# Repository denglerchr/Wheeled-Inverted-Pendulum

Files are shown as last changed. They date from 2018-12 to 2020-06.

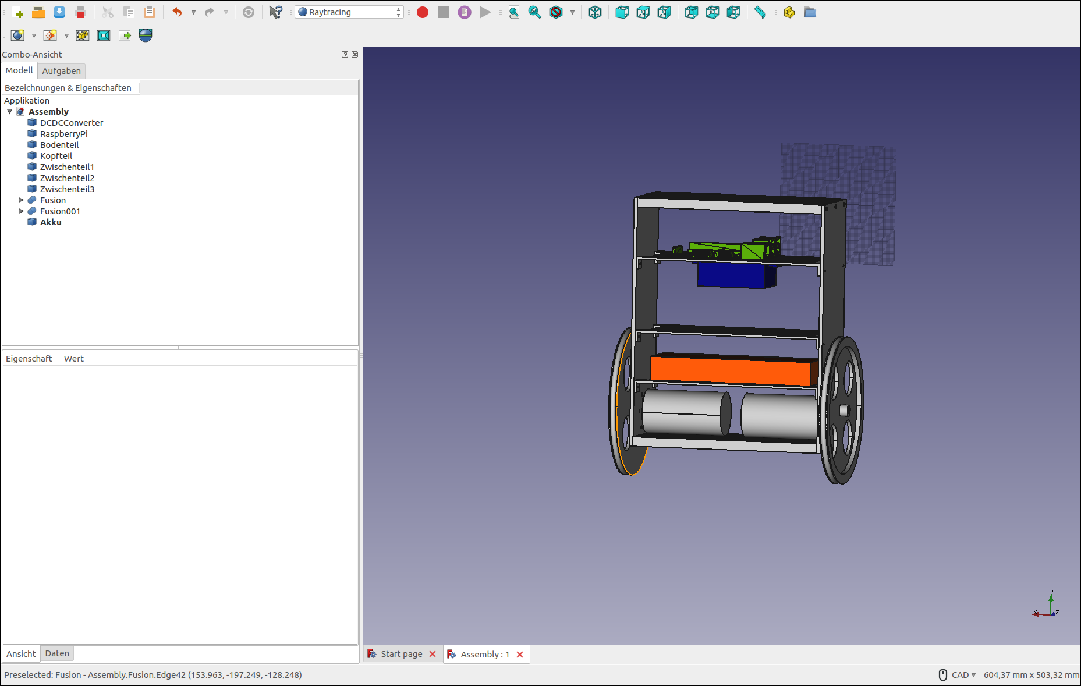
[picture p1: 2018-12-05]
01_Hardware/01_Construction/PDF/Gesamt.png

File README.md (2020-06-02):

# Wheeled-Inverted-Pendulum
## Description
This repo contains the required resources to build and deploy a relatively inexpensive wheeled inverted pendulum. It was build to provide an easily upgradable and programmable test-bed for control algorithms. The final robot can be programmed in python and accesses via wifi. It can compute computationally heavy (-> compared to other stuff done in control community) control algorithms on the raspberry pi, e.g. evaluate a neural network of mediocre size.

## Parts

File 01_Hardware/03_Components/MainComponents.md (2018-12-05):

This list is not complete yet. TODO

| Name 	| Description 	| Quantity needed 	| Approx. price 	| Online resource 	|
|:---:	|:---:	|:---:	|:---:	|:---:	|
| 2X FLOUREON 11.1V 3000mAh 30C Lipo RC Akku 	| 12V Battery, powers the robot 	| 1 	| 35€ for 2 	| https://www.amazon.de/FLOUREON%C2%AE-3000mAh-Dean-Style-Hubschrauber-Flugzeug/dp/B00Q4O6IM0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 	|
| Teensy 3.6 board 	|  Microcontroller, reading sensor data and doing all the real time stuff 	| 1 	| 30€ 	| 	|
| Raspberry Pi 3B+ 	|  Small PC, can do more heavy computations compared to the microcontroller, used e.g. for evaluating neural networks 	| 1 	| 35€ 	| 	|
| Dual 6A DC Motor Driver 	|  H-bridges, used to transform the microcontroller signal into the voltage that the motor needs 	| 1 	| 20€ 	| http://www.hobbytronics.co.uk/dual-6a-dc-motor-controller 	|
| MPU-6050 	|  Circuit with accelerometer and gyroscope, can be read out using I2C. 	| 1 	| 3.5€ 	| 
|12V DC Motor with encoder | The motors that allow the robot to move around. The 292 rpm motor in the link provides a good balance between power and speed. The encoders are sensors, required to compute the velocity and position of the robot. | 2 | 2*35€ | https://www.cqrobot.com/Gear-Ratio-18.8to1-Metal-DC-Geared-Motor-Encoder?search=dc%20motor%20&description=true | 
| SMD Capacitors (1206) | Mainly used to store electrical charges, protect consumers from power fluctuations and help with smoothing spikes in power consumption, e.g. sudden acceleration of the robot.  | 5 (10uF) | 5€ | |
| SMD Resistors (1206)| Used near the analog input of the microcontroller. Divide the battery voltage by 4, so that the microcontroller can read it. | 1 (3.3k) ; 1 (10k) | 2€||
| Connectors  and cables| To attach the components to the main circuit board, cables and connectors are needed. | tbd | ??€||

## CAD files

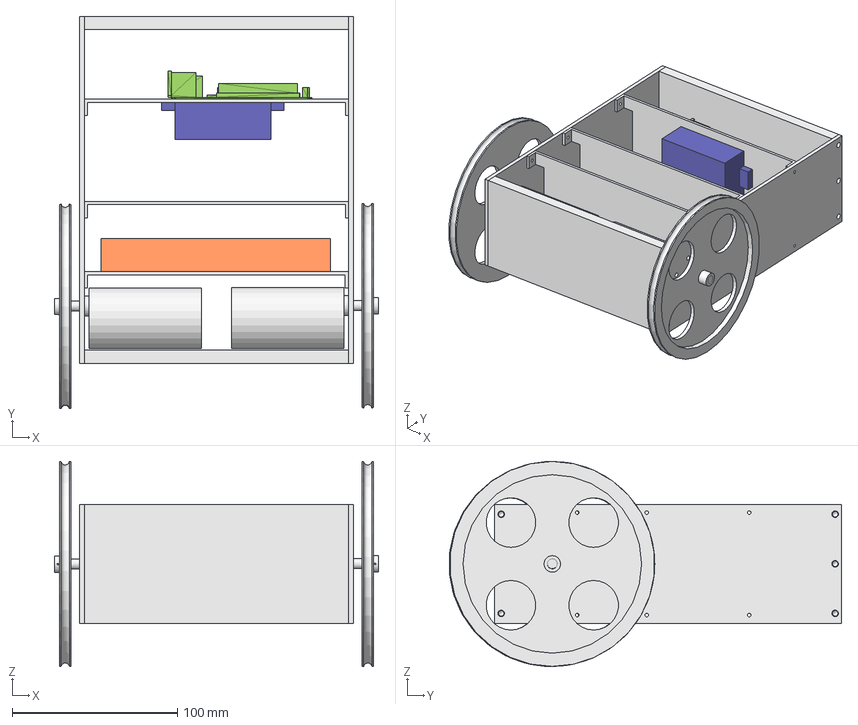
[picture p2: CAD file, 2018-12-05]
01_Hardware/01_Construction/Assembly.fcstd
196.0 x 237.4 x 124.1 mm
DCDCConverter
RaspberryPi
Bodenteil
Kopfteil
Zwischenteil1
Zwischenteil2
Zwischenteil3
Akku

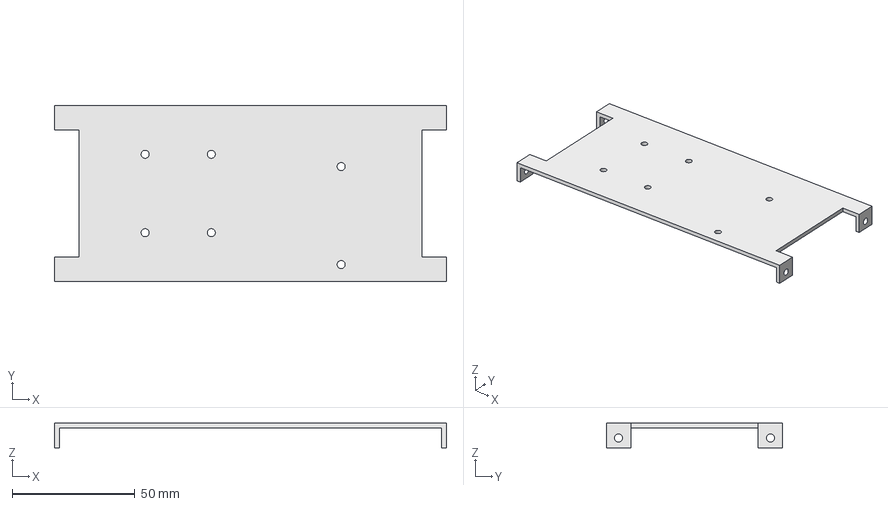
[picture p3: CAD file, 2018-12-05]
01_Hardware/01_Construction/Zwischenblech_teensy.fcstd
160.0 x 72.0 x 10.0 mm

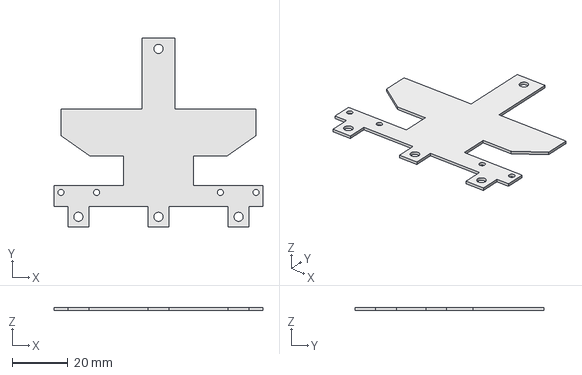
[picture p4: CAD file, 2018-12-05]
01_Hardware/01_Construction/Distanzsensor_Halterung.fcstd
75.0 x 68.0 x 1.00 mm

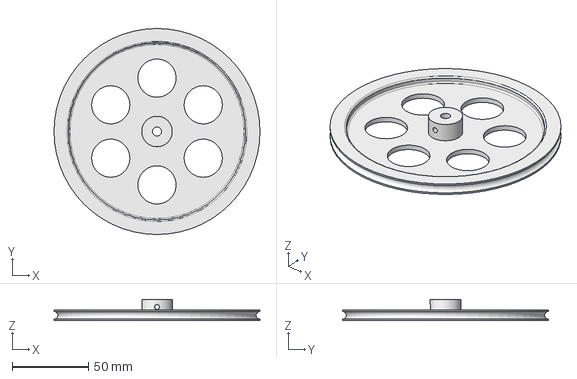
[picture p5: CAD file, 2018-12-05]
01_Hardware/01_Construction/Rad.fcstd
135.0 x 135.0 x 14.0 mm

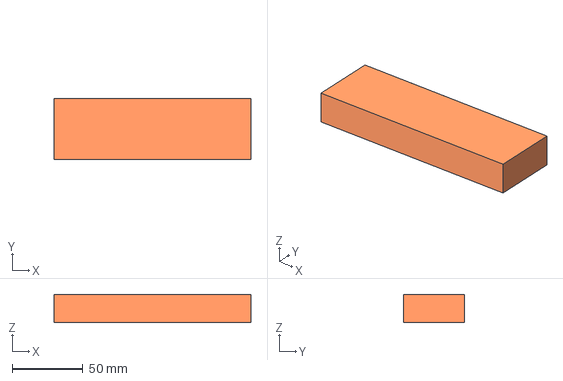
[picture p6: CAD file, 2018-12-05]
01_Hardware/01_Construction/Akku.fcstd
139.0 x 43.0 x 20.0 mm

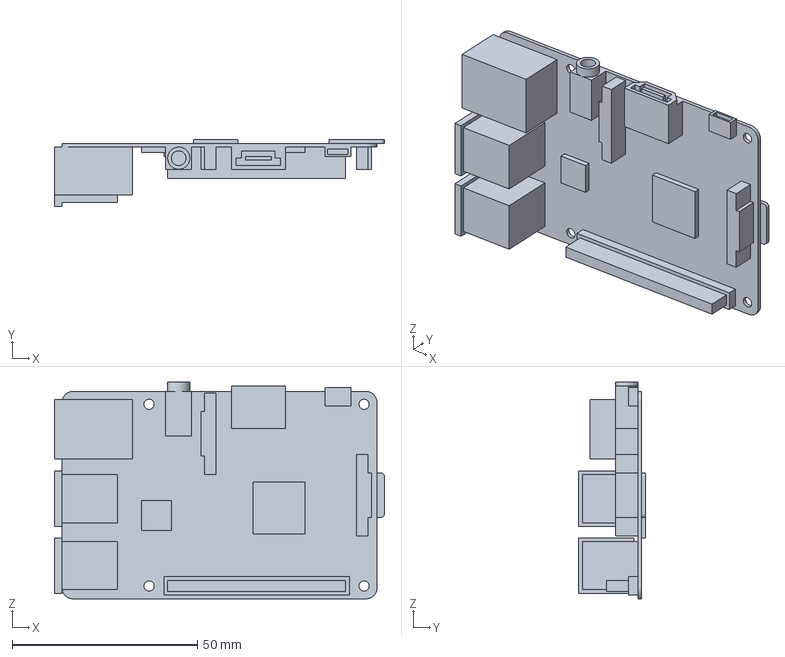
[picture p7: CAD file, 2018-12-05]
01_Hardware/01_Construction/Raspberry_Pi3b.fcstd
89.0 x 18.0 x 58.5 mm

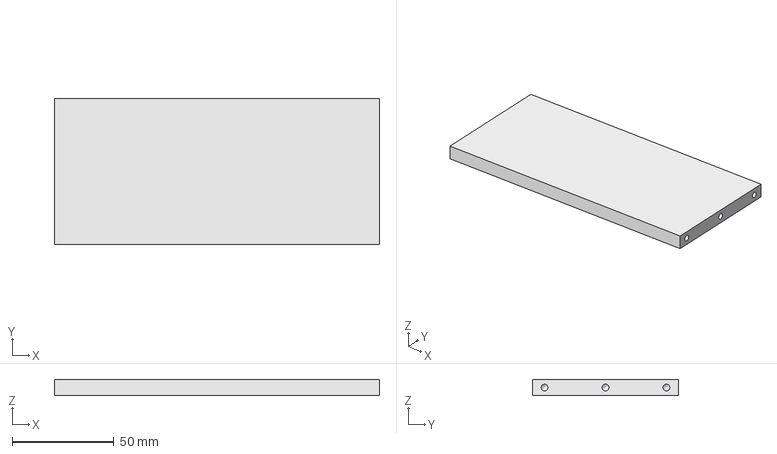
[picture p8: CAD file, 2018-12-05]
01_Hardware/01_Construction/Dach.fcstd
160.0 x 72.0 x 8.00 mm

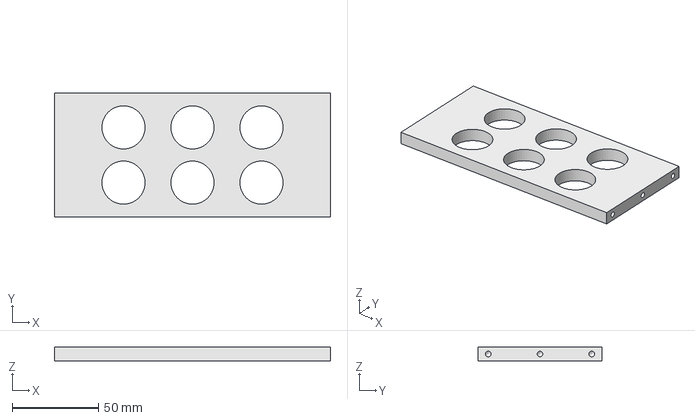
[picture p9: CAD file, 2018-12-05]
01_Hardware/01_Construction/Boden.fcstd
160.0 x 72.0 x 8.00 mm

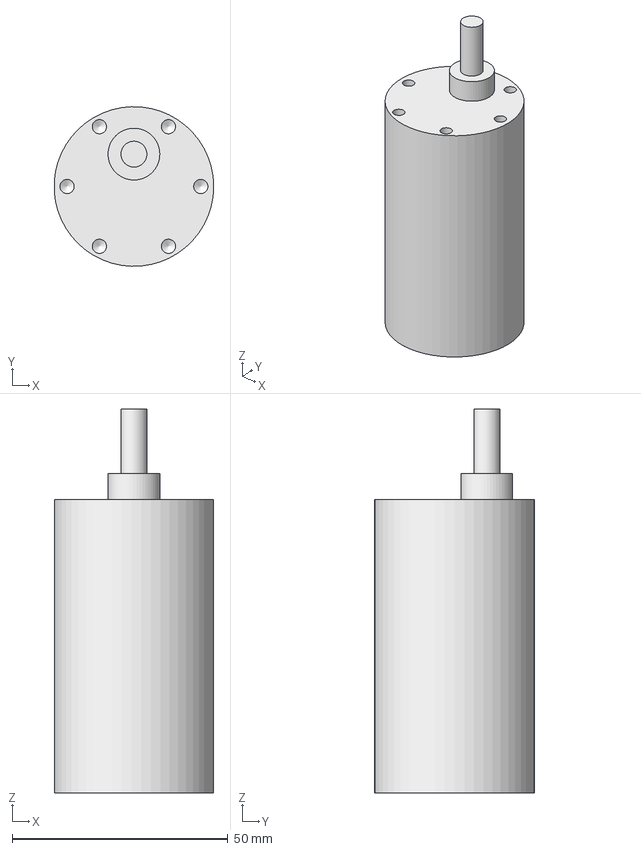
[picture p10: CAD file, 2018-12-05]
01_Hardware/01_Construction/Motor.fcstd
37.0 x 37.0 x 89.0 mm

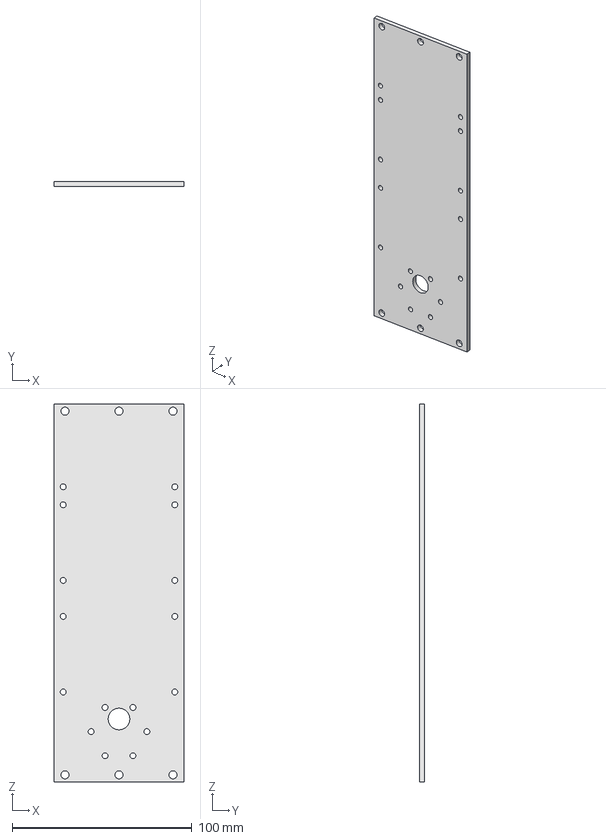
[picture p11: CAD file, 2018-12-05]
01_Hardware/01_Construction/Seitenblech.fcstd
72.0 x 3.00 x 210.0 mm

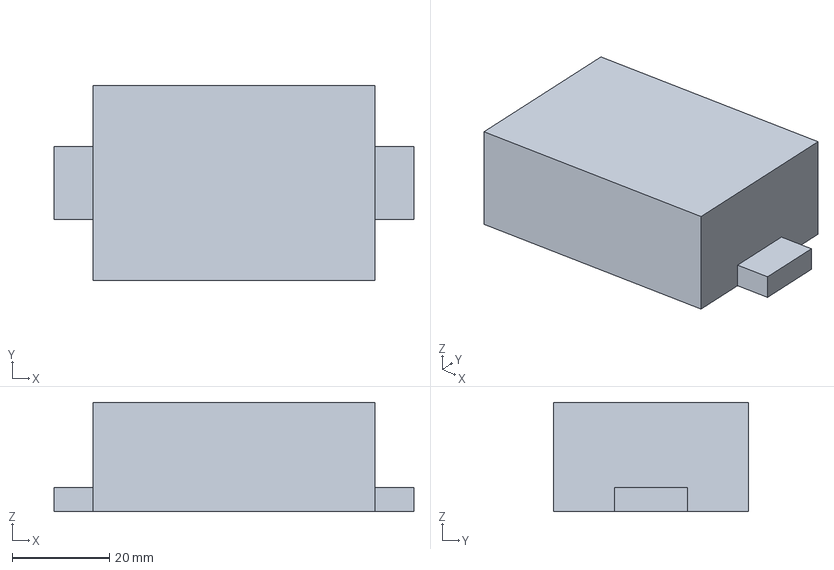
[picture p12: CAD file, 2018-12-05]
01_Hardware/01_Construction/12to5V_Converter.fcstd
74.0 x 40.0 x 22.5 mm

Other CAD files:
01_Hardware/01_Construction/Zwischenblech_rpi.fcstd
01_Hardware/01_Construction/Zwischenblech_akku.fcstd
01_Hardware/01_Construction/Zwischenblech.fcstd

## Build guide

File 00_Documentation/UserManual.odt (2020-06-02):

User Manual: Building and using a Wheeled Inverted Pendulum

This document is concerned with building and using a small balancing robot, with resources available under: https://github.com/denglerchr/Wheeled-Inverted-Pendulum

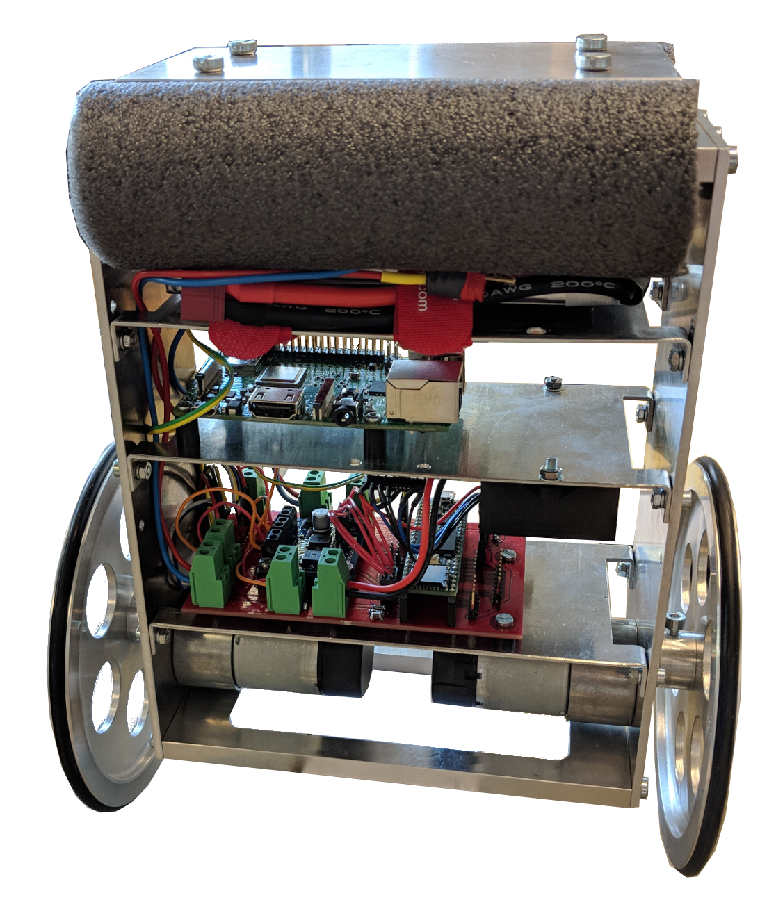
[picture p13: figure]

Authors:
Christian Dengler

# Components and electronics setup

## Components

The components are relatively inexpensive and the setup is modular, as such, even if a part is not available anymore, it should be possible to upgrade the Raspberry. The wheeled inverted pendulum (WIP), as of early 2020, consists of the following parts:

Energy supply:

- 12V (11.1V) battery

Actuators:

- DC Motors with Encoder

Sensors:

- Accelerometer+gyroscope, type MPU6050
- (Encoders on the motors)

Computing Units:

- Arduino IDE compatible microcontroller board: Teensy 3.6
- Single board compute, Raspberry PI 3B+

Further Parts:

- Dual H-bridge from HobbyTronics
- CircuitBoard, custom made, files given in the Github repo
- DCDC converter to get 5V and 3.3V required for some parts

## General Setup

The WIP contains two computing units. The Teensy is a microcontroller that is real time capable. The Raspberry Pi is more of a computer type and brings increased computing pwoer, but is unsuited for precise timings. As such, the Teensy is the master, giving the timing, whereas the Raspberry Pi is just a computing unit, reacting to the calls from the Teeny. The communication between both is serial (UART).

The main communication loop on the Teensy is as follows

1. The Teensy board reads out the encoder values and the gyroscope and the accelerometer values.
2. The Teensy transforms the sensor data into a state vector, containing the position, velocity as well as angles and angular velocities.
3. The Teensy reads the input buffer (i.e. the data the Raspberry Pi sent last cycle) and sends the state vector to the Raspberry Pi. If no data is available from the Raspberry Pi, the teensy will not send and wait, it will however always keep updating its state vector each cycle.
4. The Teensy can send some information to a PC at this point, if the specific line is uncommented, this is usefull for debugging and testing.

The main communication loop on the Raspberry Pi is:

1. Wait for data, i.e., to have 7 Float32 values = 7*4 bytes of data.
2. Compute control law and save state and action in a Matrix.
3. Send 2*4 bytes to the Teensy board and go into a waiting state until the next state vector is received. If enough time passed, print to PC.

If Keyboard-Interrupt→ stop main cycle and save the data matrix in a hdf5 file

## Schematics

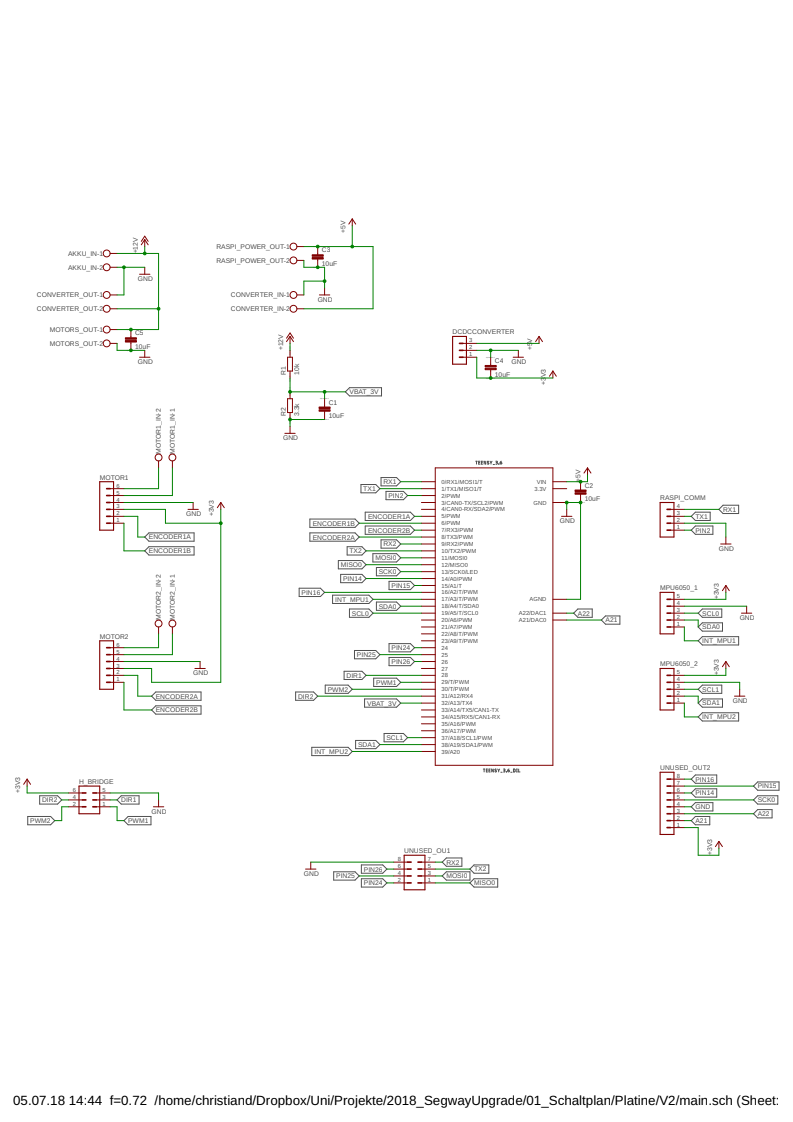
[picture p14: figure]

# Setting up the Teensy

# Setting up the Raspberry PI

## Preparing your computer and the microcontroller (Linux Version)

## Preparing the Raspberry Pi

# Starting a control algorithm

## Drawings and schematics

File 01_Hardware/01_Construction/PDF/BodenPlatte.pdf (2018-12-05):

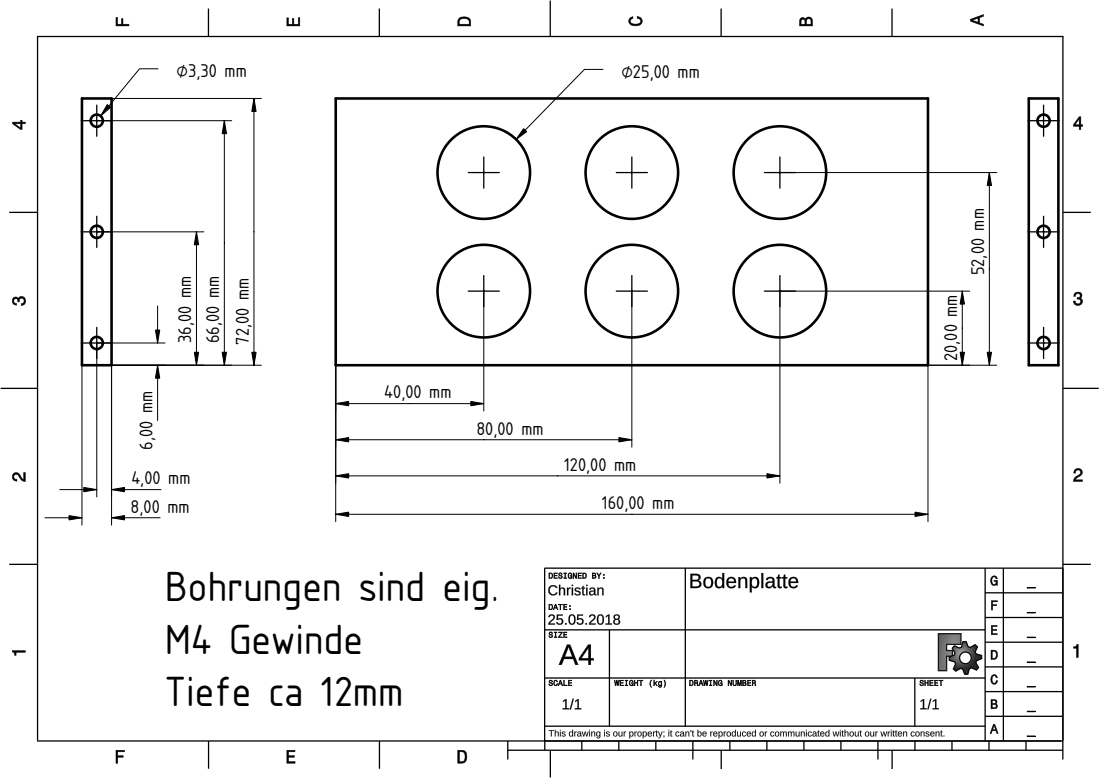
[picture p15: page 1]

Bohrungen sind eig. M4 Gewinde
Tiefe ca 12mm

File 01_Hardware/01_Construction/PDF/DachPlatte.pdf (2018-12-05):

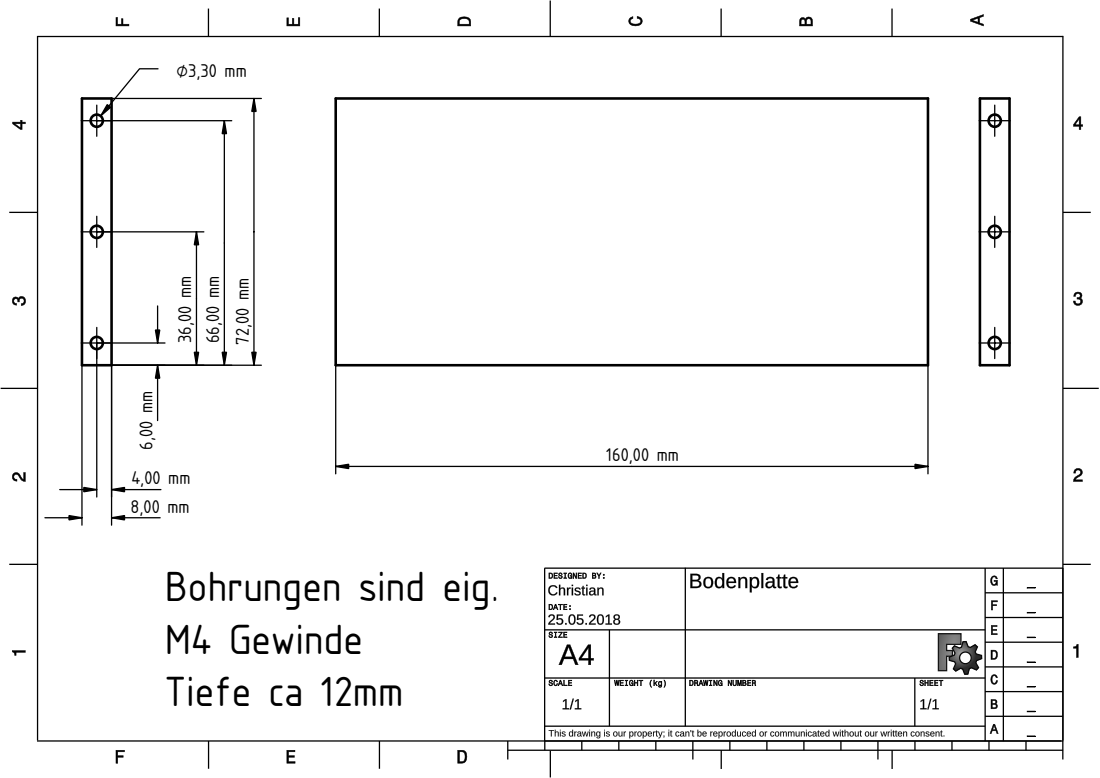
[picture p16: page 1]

Bohrungen sind eig. M4 Gewinde
Tiefe ca 12mm

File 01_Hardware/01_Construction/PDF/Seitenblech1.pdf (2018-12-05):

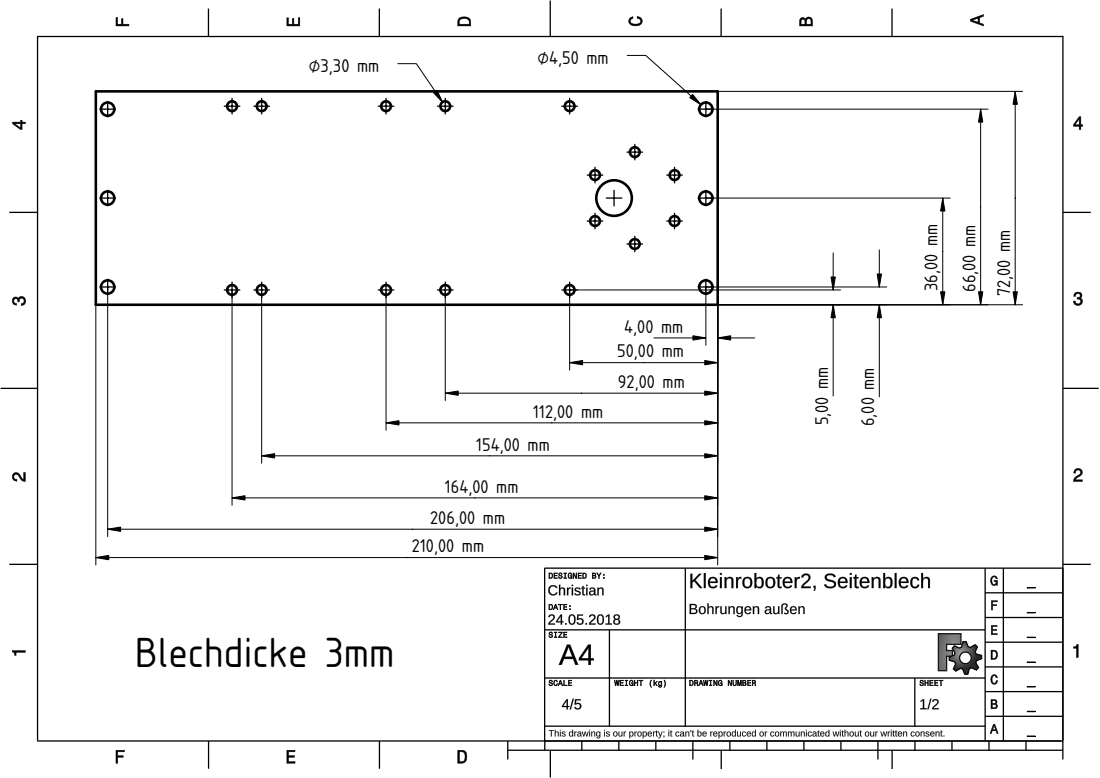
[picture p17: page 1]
Blechdicke 3mm

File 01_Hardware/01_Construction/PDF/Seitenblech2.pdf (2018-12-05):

h7

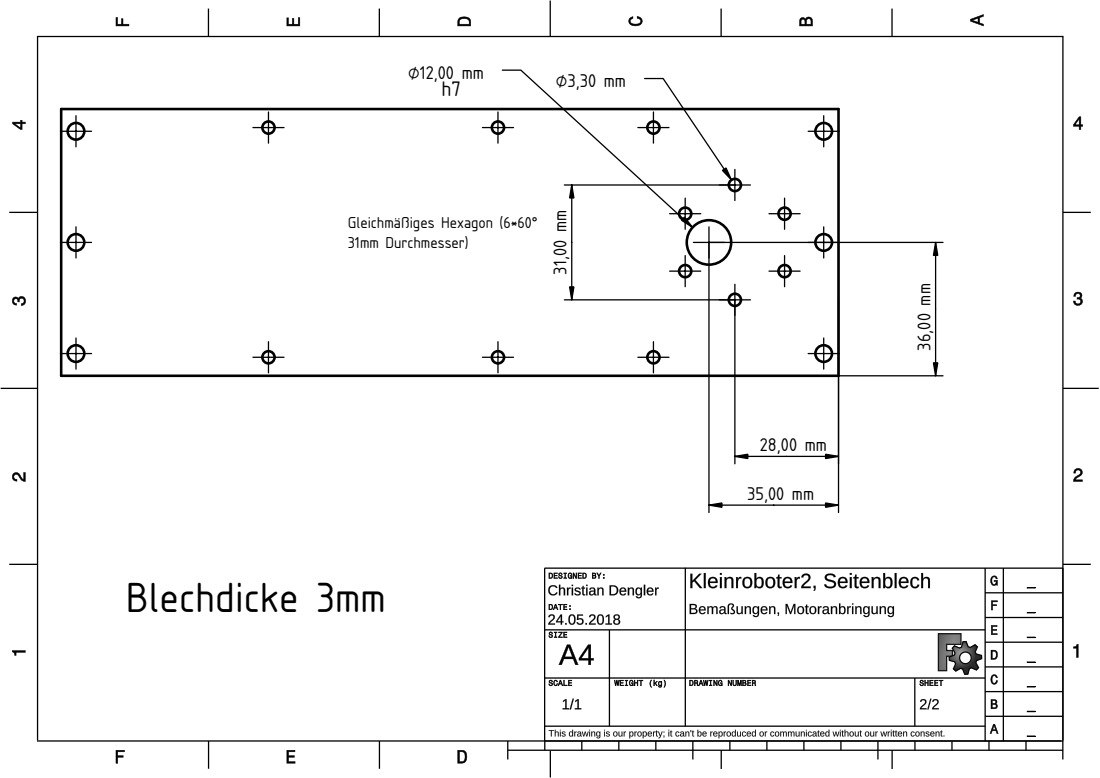
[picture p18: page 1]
Blechdicke 3mm; Gleichmäßiges Hexagon (6*60° 31mm Durchmesser)

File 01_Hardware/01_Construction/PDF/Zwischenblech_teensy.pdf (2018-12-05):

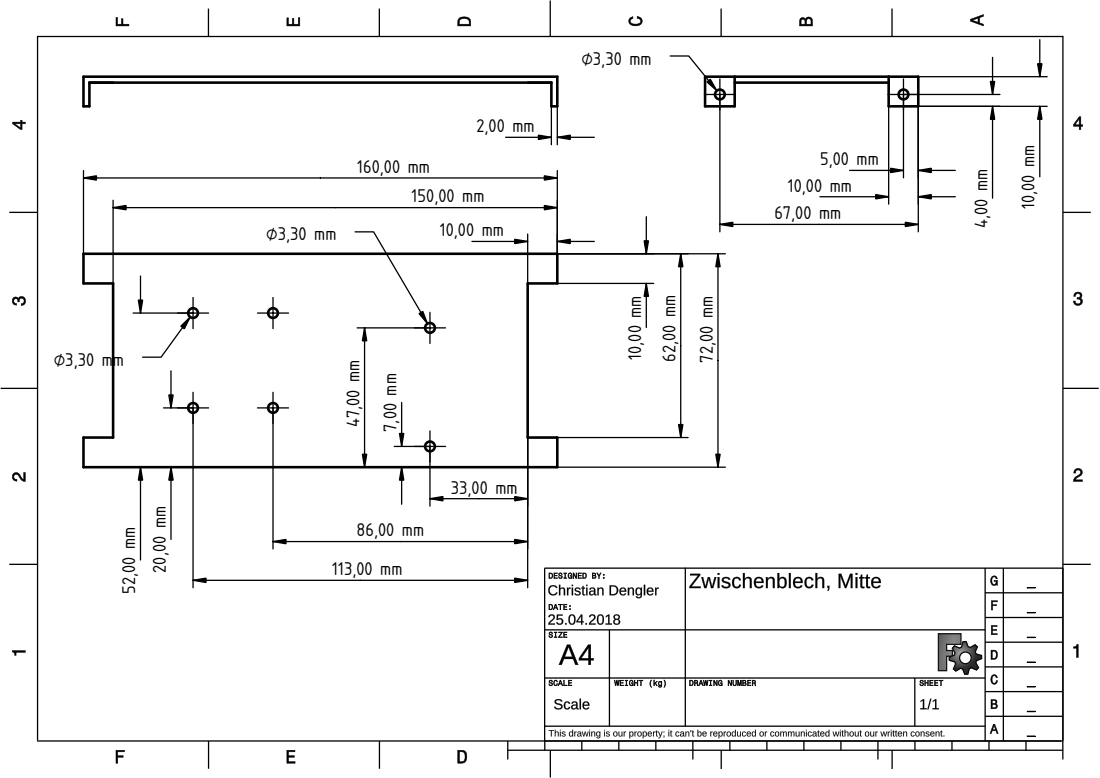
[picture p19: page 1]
m 113,00 mm⁷,00 mm 47,00 m

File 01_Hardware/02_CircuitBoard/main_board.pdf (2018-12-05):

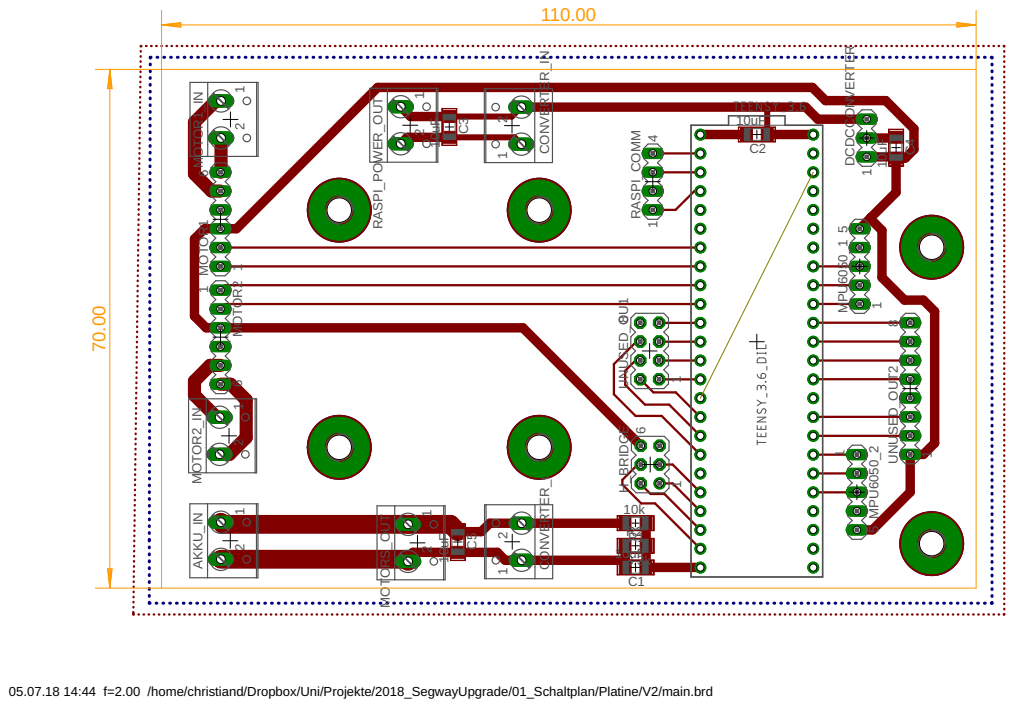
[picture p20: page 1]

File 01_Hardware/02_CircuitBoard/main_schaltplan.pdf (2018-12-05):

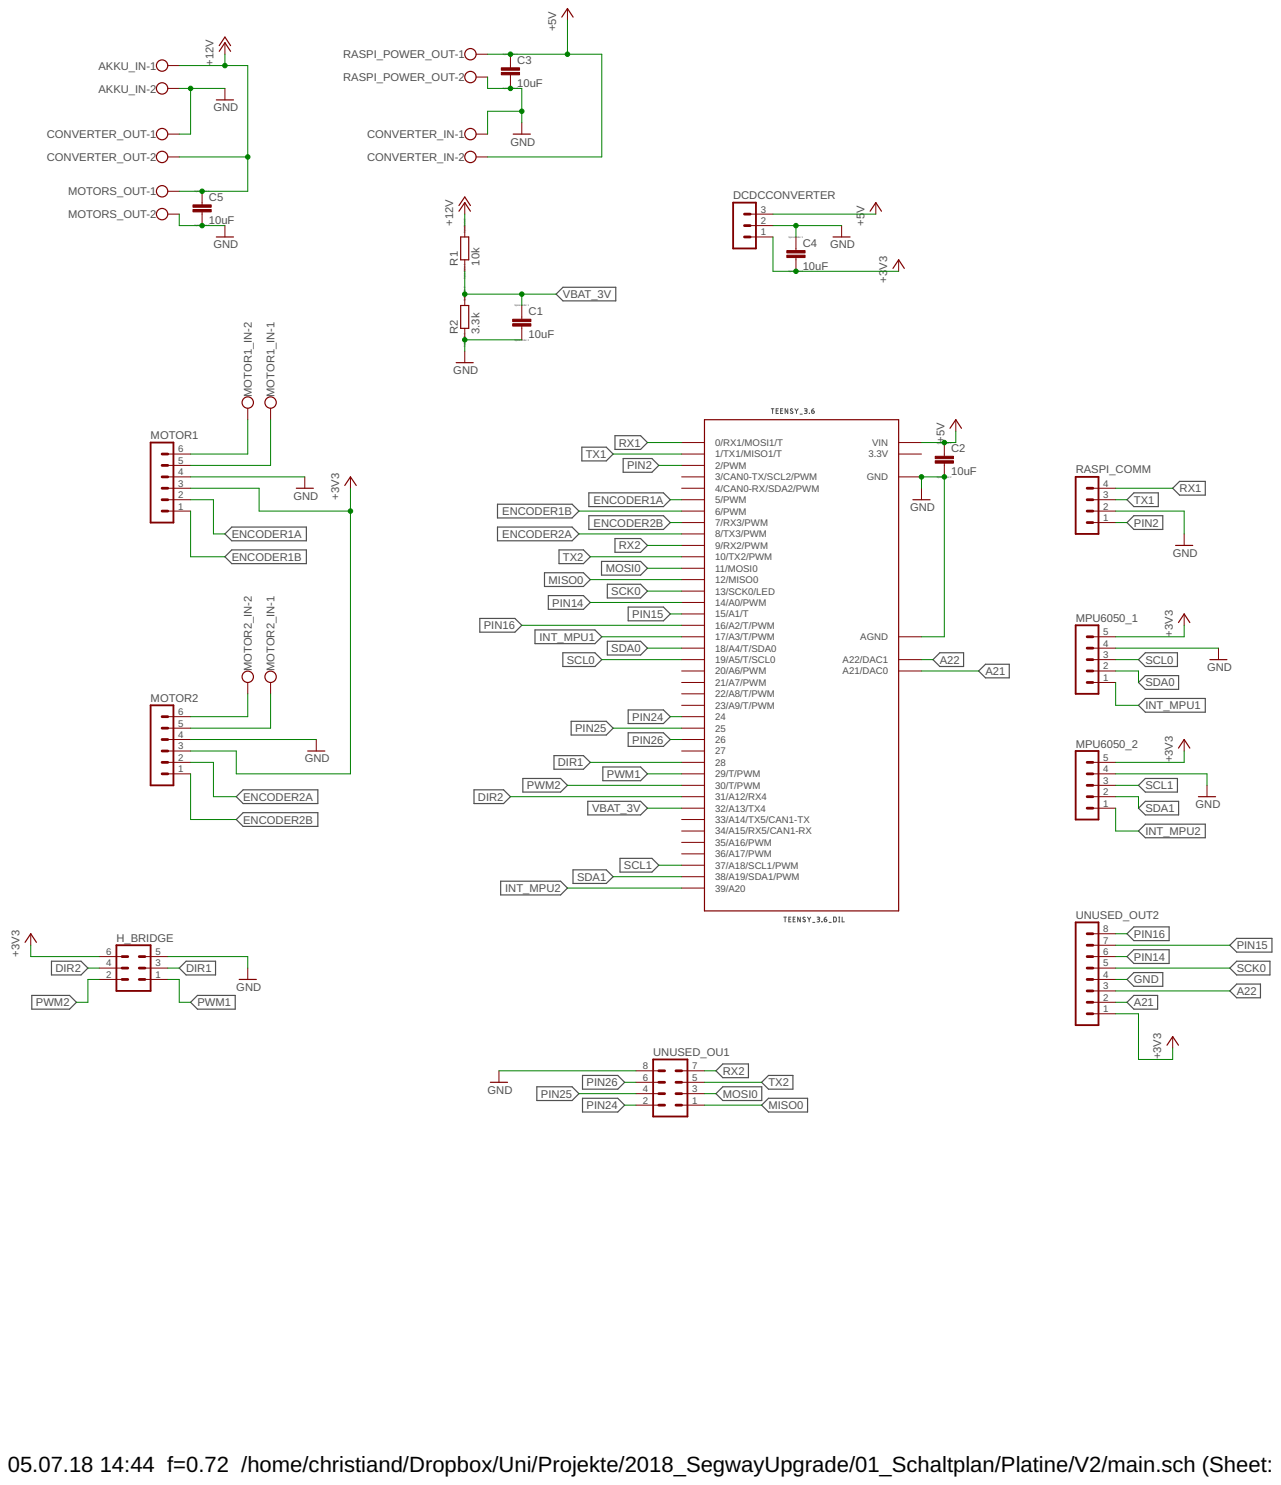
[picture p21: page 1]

SpiceOrder 1 SpiceOrder 2

DIR2 4 | 3 DIR1

PIN25 4 | 3 MOSI0 1

05.07.18 14:44 f=0.72 /home/christiand/Dropbox/Uni/Projekte/2018_SegwayUpgrade/01_Schaltplan/Platine/V2/main.sch (Sheet: 1/1)

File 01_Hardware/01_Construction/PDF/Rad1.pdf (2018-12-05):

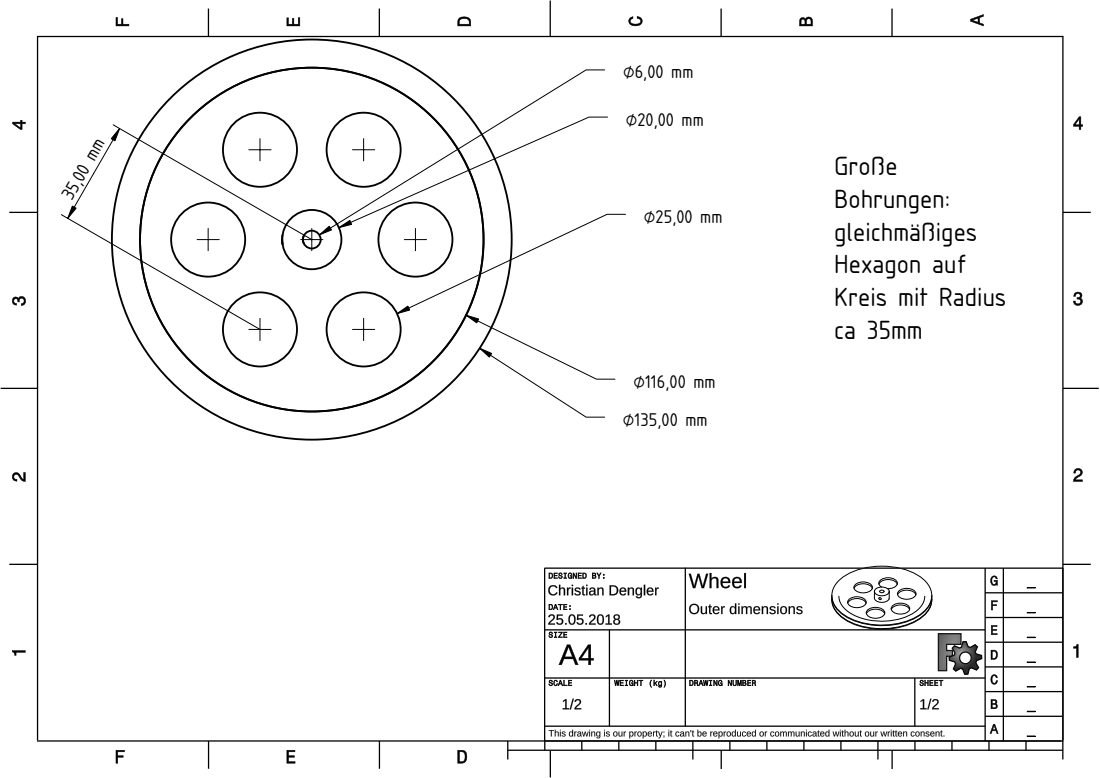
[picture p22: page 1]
Gro; hru; n: gleichmäßig; diu

uf Kreis mit Ra

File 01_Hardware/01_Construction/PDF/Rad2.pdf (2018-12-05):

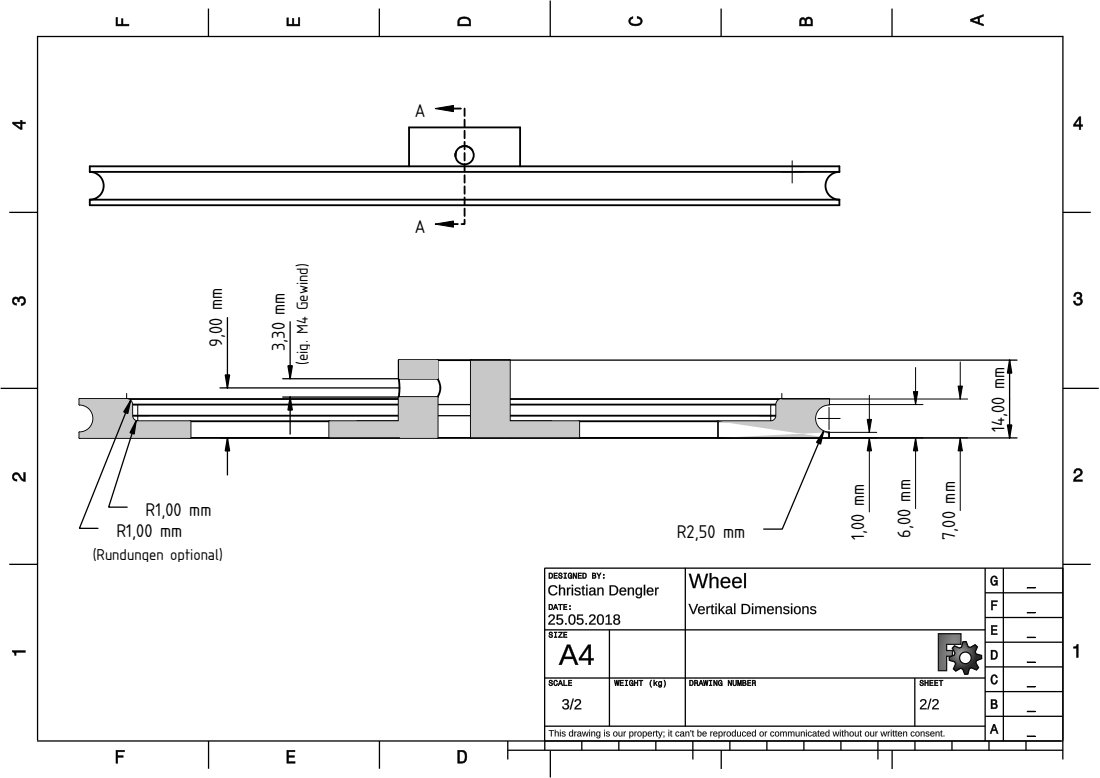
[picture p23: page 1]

(eig. M4 Gewind) (Rundungen optional)

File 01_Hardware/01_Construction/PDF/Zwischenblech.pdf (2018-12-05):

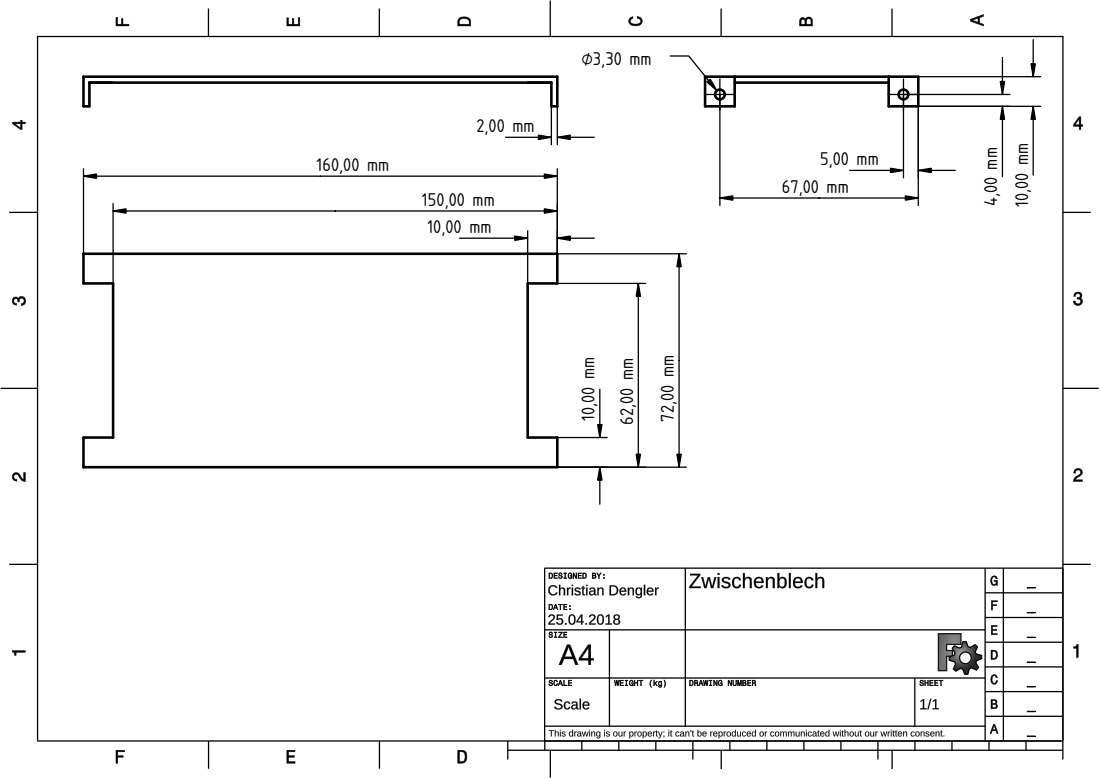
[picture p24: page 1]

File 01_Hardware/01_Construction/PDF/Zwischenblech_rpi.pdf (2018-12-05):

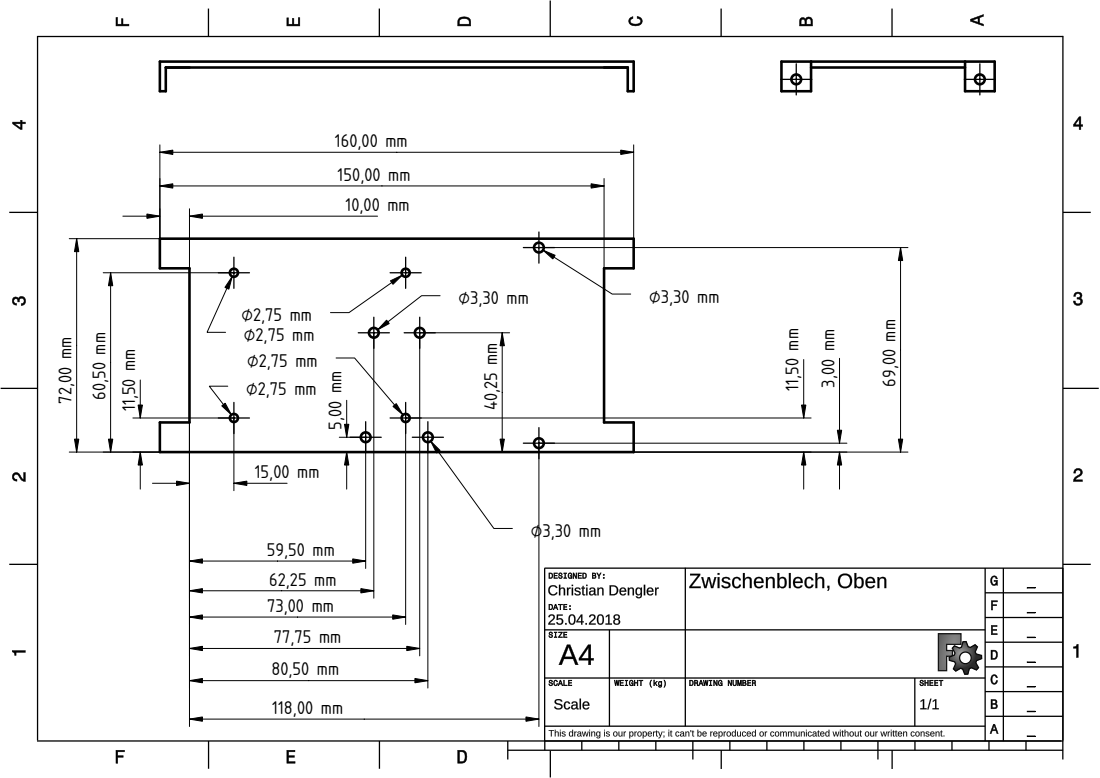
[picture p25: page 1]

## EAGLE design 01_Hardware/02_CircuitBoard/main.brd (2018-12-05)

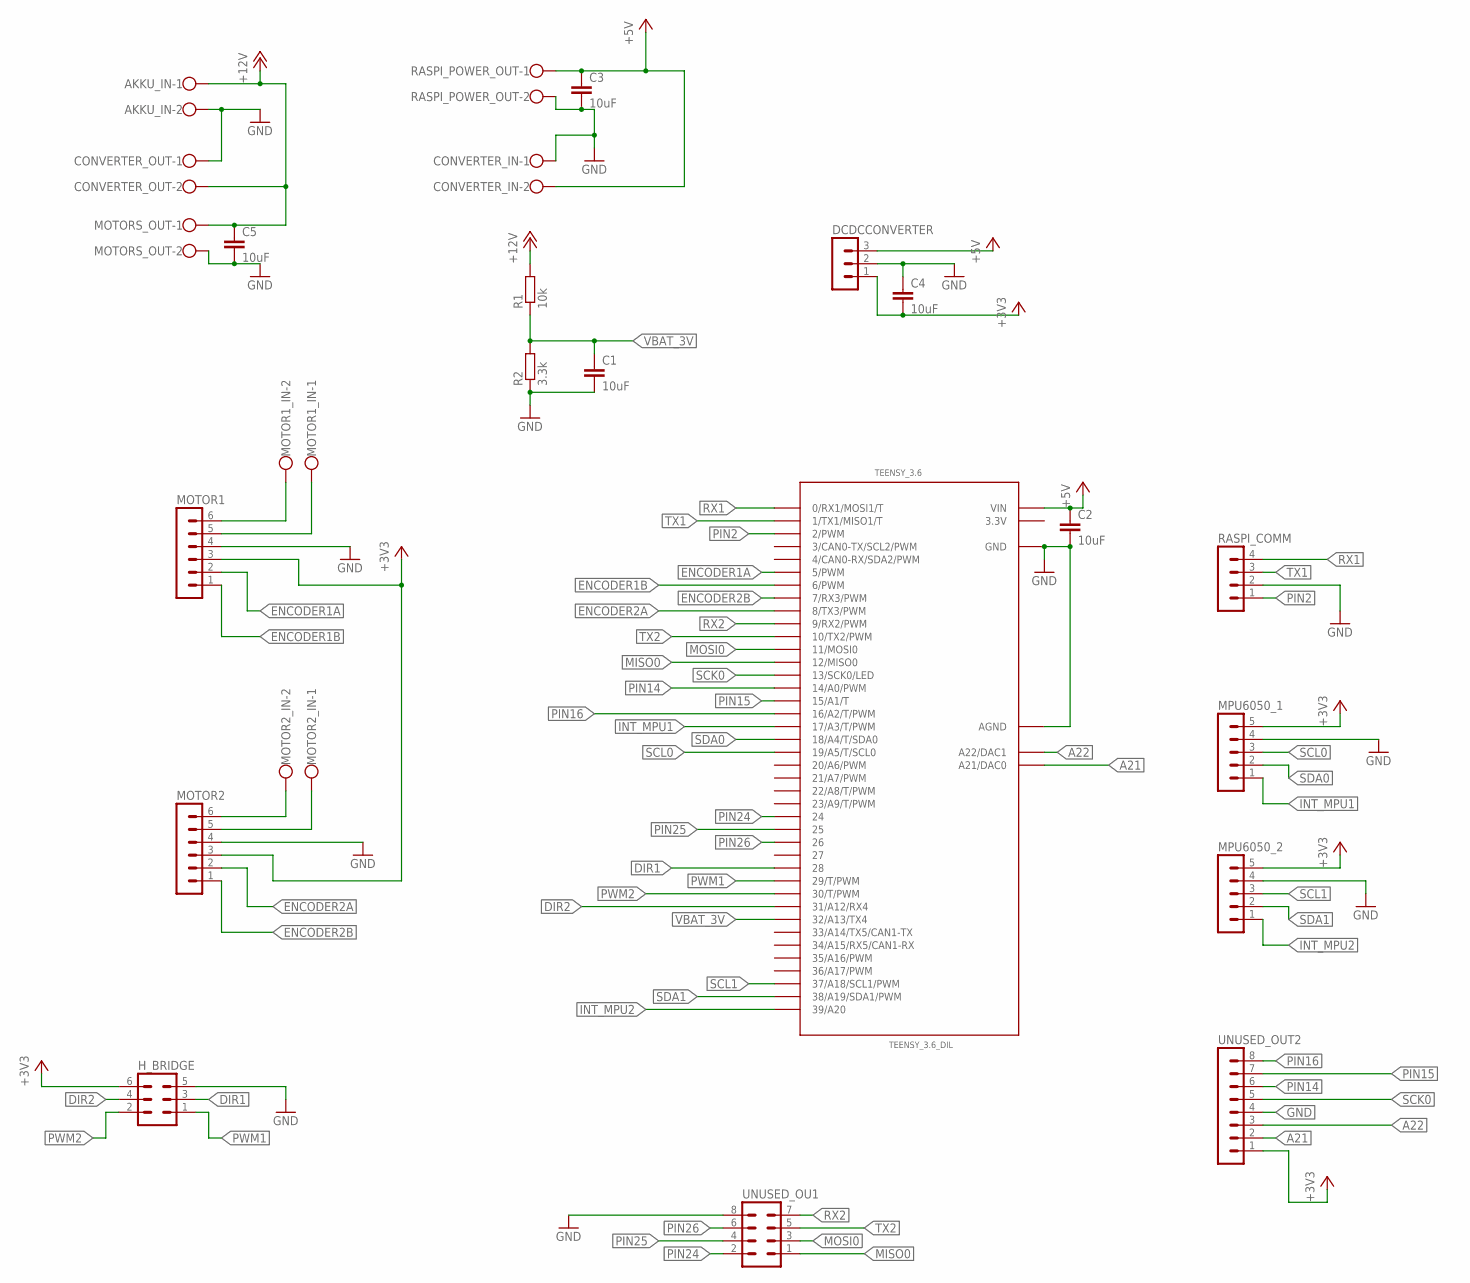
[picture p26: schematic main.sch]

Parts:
AKKU_IN: W237-102
C1, C2, C3, C4, C5: 10uF; C1206
CONVERTER_IN: W237-102
CONVERTER_OUT: W237-102
DCDCCONVERTER: MA03-1
H_BRIDGE: MA03-2
MOTOR1, MOTOR2: MA06-1
MOTOR1_IN, MOTOR2_IN: W237-102
MOTORS_OUT: W237-102
MPU6050_1, MPU6050_2: MA05-1
R1: 10k; R1206
R2: 3.3k; R1206
RASPI_COMM: MA04-1
RASPI_POWER_OUT: W237-102
TEENSY_3.6: TEENSY_3.6_DIL
UNUSED_OU1: MA04-2
UNUSED_OUT2: MA08-1

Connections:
3.3V: TEENSY_3.6.3.3V, TEENSY_3.6.3.3V3 (3.3V)
+3V3: C4.2, DCDCCONVERTER.1, H_BRIDGE.6, MOTOR1.3, MOTOR2.3, MPU6050_1.5, MPU6050_2.5, UNUSED_OUT2.1
+5V: C2.1, C3.1, CONVERTER_IN.2, DCDCCONVERTER.3, RASPI_POWER_OUT.1, TEENSY_3.6.VIN
+12V: AKKU_IN.1, C5.1, CONVERTER_OUT.2, MOTORS_OUT.1, R1.2
A21: TEENSY_3.6.A21 (A21/DAC0), UNUSED_OUT2.2
A22: TEENSY_3.6.A22 (A22/DAC1), UNUSED_OUT2.3
DIR1: H_BRIDGE.3, TEENSY_3.6.28
DIR2: H_BRIDGE.4, TEENSY_3.6.31/A12 (31/A12/RX4)
ENCODER1A: MOTOR1.2, TEENSY_3.6.5 (5/PWM)
ENCODER1B: MOTOR1.1, TEENSY_3.6.6 (6/PWM)
ENCODER2A: MOTOR2.2, TEENSY_3.6.8 (8/TX3/PWM)
ENCODER2B: MOTOR2.1, TEENSY_3.6.7 (7/RX3/PWM)
GND: AKKU_IN.2, C1.2, C2.2, C3.2, C4.1, C5.2, CONVERTER_IN.1, CONVERTER_OUT.1, DCDCCONVERTER.2, H_BRIDGE.5, MOTOR1.4, MOTOR2.4, MOTORS_OUT.2, MPU6050_1.4, MPU6050_2.4, R2.1, RASPI_COMM.2, RASPI_POWER_OUT.2, TEENSY_3.6.AGND, TEENSY_3.6.GND, TEENSY_3.6.GND1 (GND), UNUSED_OU1.8, UNUSED_OUT2.4
INT_MPU1: MPU6050_1.1, TEENSY_3.6.17/A3 (17/A3/T/PWM)
INT_MPU2: MPU6050_2.1, TEENSY_3.6.39/A20
MISO0: TEENSY_3.6.12 (12/MISO0), UNUSED_OU1.1
MOSI0: TEENSY_3.6.11 (11/MOSI0), UNUSED_OU1.3
MOTOR1+: MOTOR1.6, MOTOR1_IN.2
MOTOR1-: MOTOR1.5, MOTOR1_IN.1
MOTOR2+: MOTOR2.6, MOTOR2_IN.2
MOTOR2-: MOTOR2.5, MOTOR2_IN.1
PIN2: RASPI_COMM.1, TEENSY_3.6.2 (2/PWM)
PIN14: TEENSY_3.6.14/A0 (14/A0/PWM), UNUSED_OUT2.6
PIN15: TEENSY_3.6.15/A1 (15/A1/T), UNUSED_OUT2.7
PIN16: TEENSY_3.6.16/A2 (16/A2/T/PWM), UNUSED_OUT2.8
PIN24: TEENSY_3.6.24, UNUSED_OU1.2
PIN25: TEENSY_3.6.25, UNUSED_OU1.4
PIN26: TEENSY_3.6.26, UNUSED_OU1.6
PWM1: H_BRIDGE.1, TEENSY_3.6.29 (29/T/PWM)
PWM2: H_BRIDGE.2, TEENSY_3.6.30 (30/T/PWM)
RX1: RASPI_COMM.4, TEENSY_3.6.0 (0/RX1/MOSI1/T)
RX2: TEENSY_3.6.9 (9/RX2/PWM), UNUSED_OU1.7
SCK0: TEENSY_3.6.13 (13/SCK0/LED), UNUSED_OUT2.5
SCL0: MPU6050_1.3, TEENSY_3.6.19/A5 (19/A5/T/SCL0)
SCL1: MPU6050_2.3, TEENSY_3.6.37/A18 (37/A18/SCL1/PWM)
SDA0: MPU6050_1.2, TEENSY_3.6.18/A4 (18/A4/T/SDA0)
SDA1: MPU6050_2.2, TEENSY_3.6.38/A19 (38/A19/SDA1/PWM)
TX1: RASPI_COMM.3, TEENSY_3.6.1 (1/TX1/MISO1/T)
TX2: TEENSY_3.6.10 (10/TX2/PWM), UNUSED_OU1.5
VBAT_3V: C1.1, R1.1, R2.2, TEENSY_3.6.32/A13 (32/A13/TX4)

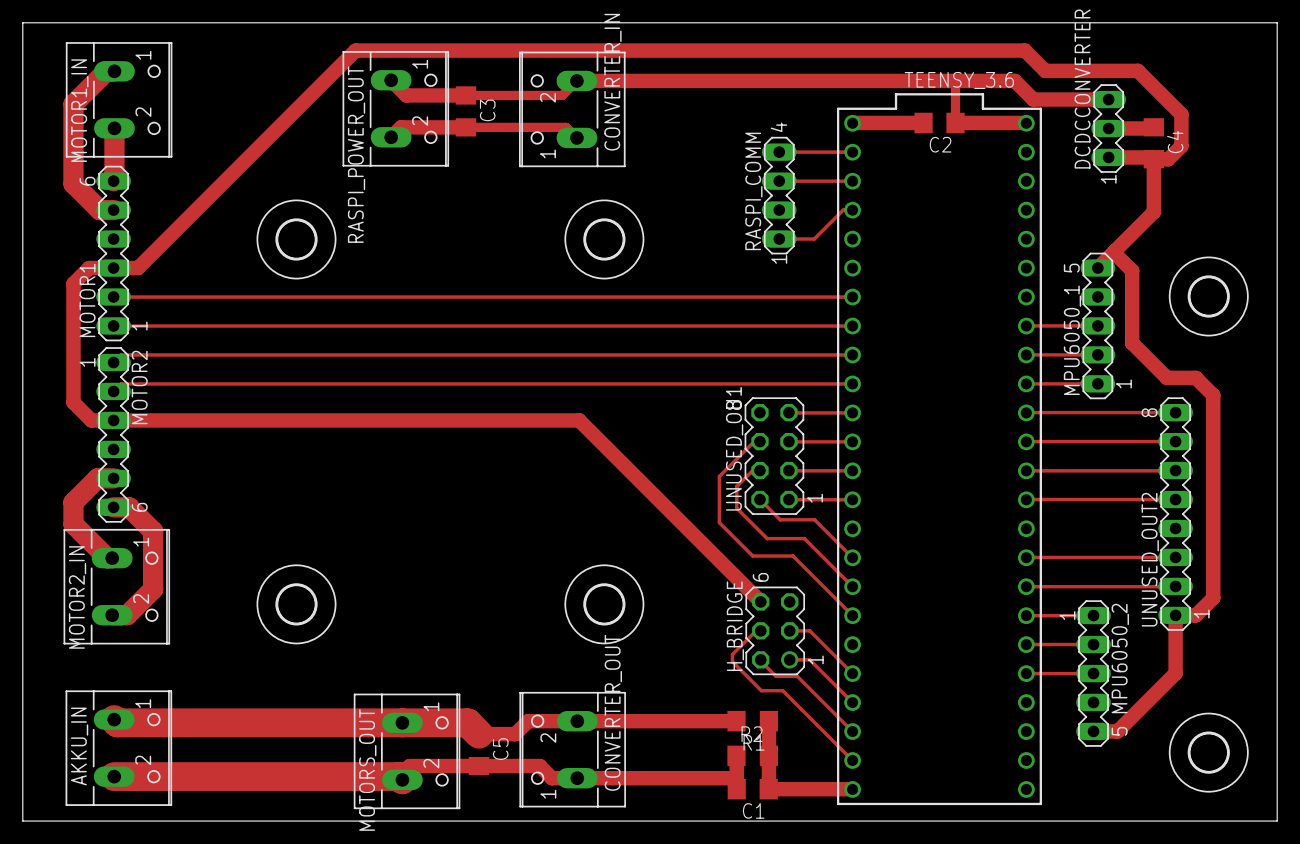
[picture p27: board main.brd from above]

Board: 2 copper layers, 110.0 x 70.0 mm, 30 parts (0 on the bottom side), 40 nets.

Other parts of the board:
U$1, U$2, U$3, U$4, U$5, U$6: 3,3

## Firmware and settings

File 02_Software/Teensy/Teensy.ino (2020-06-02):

// This is the main programm for the small inverted pendulum on wheels
// The programm reads the sensors, uses the data to create a state vector
// and send it to the raspberry pi.
//
// TODO: Handle NaN, which can appear when interrupting the rapsberry pi somehow
//
// Include Libraries
//#include "I2Cdev.h"
#include <math.h>
#include "MPU6050_6Axis_MotionApps20.h"
#include "Wire.h"
#include <Encoder.h>

#include "pindef.h" // Contains all the Pin definitions
#include "vars_and_types.h"

//Some helper functions
void dmpDataReady() {
  mpuInterrupt = true;
}

template <typename T> int sign(T val) {
    return (T(0) < val) - (val < T(0));
}

// This is running once at the beginning
void setup() {
  // Serial connections
  Serial.begin(9600); //to communicate with the PC during setup
  RASPBERRY_SERIAL.begin(1000000); //communication with the raspberry pi

  //I2C communication
  Wire.begin();
  Wire.setClock(400000); // 400kHz I2C clock. Comment this line if having compilation difficulties

  //mpu setup
  Serial.println(F("Testing device connections..."));
  mpu.initialize();
  pinMode(PIN_MPU_INTERRUPT, INPUT);
  Serial.println(mpu.testConnection() ? F("MPU6050 connection successful") : F("MPU6050 connection failed"));
  Serial.println(F("Initializing DMP..."));
  devStatus = mpu.dmpInitialize();
  // make sure it worked (returns 0 if so)
  if (devStatus == 0) {
    // turn on the DMP, now that it's ready
    Serial.println(F("Enabling DMP..."));
    mpu.setDMPEnabled(true);

    // enable Arduino interrupt detection
    Serial.println(F("Enabling interrupt detection (Arduino external interrupt 0)..."));
    attachInterrupt(digitalPinToInterrupt(PIN_MPU_INTERRUPT), dmpDataReady, RISING);
    mpuIntStatus = mpu.getIntStatus();

    // set our DMP Ready flag so the main loop() function knows it's okay to use it
    Serial.println(F("DMP ready! Waiting for first interrupt..."));
    dmpReady = true;

    // get expected DMP packet size for later comparison
    packetSize = mpu.dmpGetFIFOPacketSize();
  } else {
    // ERROR!
    // 1 = initial memory load failed
    // 2 = DMP configuration updates failed
    // (if it's going to break, usually the code will be 1)
    Serial.print(F("DMP Initialization failed (code "));
    Serial.print(devStatus);
    Serial.println(F(")"));
  }

  // variable initialization
  for (i=0; i<7; i++)
  {
    state[i].floatingPoint = 0.0;
  }
  for (i=0; i<2; i++)
  {
    action[i].floatingPoint = 0.0;
  }
  v_battery = 11.0;

  //LED setup
  pinMode(PIN_RED_LED, OUTPUT);

  //Motor setup
  pinMode(PIN_DIR_LEFT, OUTPUT);
  pinMode(PIN_PWM_LEFT, OUTPUT);
  pinMode(PIN_DIR_RIGHT, OUTPUT);
  pinMode(PIN_PWM_RIGHT, OUTPUT);
  digitalWrite(PIN_DIR_LEFT, LOW);
  digitalWrite(PIN_PWM_LEFT, LOW);
  digitalWrite(PIN_DIR_RIGHT, LOW);
  digitalWrite(PIN_PWM_RIGHT, LOW);

  // Start with 5s led blink
  for (i=0; i<5; i++)
  {
    digitalWrite(PIN_RED_LED, HIGH);
    delay(500);
    digitalWrite(PIN_RED_LED, LOW);
    delay(500);
  }

}

// Main loop
void loop()
{
  if (sinceStateUpdate>=DT)
  {
    sinceStateUpdate = 0;

    // Get batterie voltage (overwrites "v_battery")
    get_batterie_voltage();

    //Change encoder state if new "u" arrived
    set_motors();

    // Readout MPU if new data is available (overwrite "ypr")
    mpu_readout();

    // Read out encoders (overwrite "ds_left", "ds_right")
    read_encoder();

    // State estimation (overwrite "state" and "newdata")
    state_update();
  }

  // Raspberry pi communication if it is ready (overwrite "u")
  raspi_communication();

  //Uncomment to send data to PC
  //pc_communication();
}

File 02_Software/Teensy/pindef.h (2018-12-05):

#define PIN_RED_LED 13

// For the Raspberry Pi
#define RASPBERRY_SERIAL Serial1

// MPU interrupt pins
#define PIN_MPU_INTERRUPT 17

//Encoder pins
#define PIN_ENCODER1A 7
#define PIN_ENCODER1B 8
#define PIN_ENCODER2A 5
#define PIN_ENCODER2B 6

// Motor pins (MOTOR1 is right side and controlled by u[1])
#define PIN_PWM_LEFT 30
#define PIN_DIR_LEFT 31
#define PIN_PWM_RIGHT 29
#define PIN_DIR_RIGHT 28

//Akku voltage pin
#define PIN_AKKU_ANALOG 32

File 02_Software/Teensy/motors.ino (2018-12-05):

void set_motors()
{
  // Convert control signal (must be between -1 and 1), to a PWM signal
  // Max voltage applied is 10.5V

  //stop if battery is low or robot is at ground
  if (v_battery<10.5 || abs(ypr[1]-mpu_bias[1])>1.3)
  {
    speed_left = 0;
    speed_right = 0;
    digitalWrite(PIN_RED_LED, HIGH);
    action[0].floatingPoint = 0.0;
    action[1].floatingPoint = 0.0;
  }
  else
  {

    // Compute low level variables for the motors
    digitalWrite(PIN_RED_LED, LOW);
    speed_left = static_cast<uint8_t>(abs(action[0].floatingPoint)*10.5/v_battery*255);
    speed_right = static_cast<uint8_t>(abs(action[1].floatingPoint)*10.5/v_battery*255);
    (sign(action[0].floatingPoint)>0) ? dir_left = true : dir_left = false;
    (sign(action[1].floatingPoint)>0) ? dir_right = true : dir_right = false;
  }

  //Unocmment to overwrite to test motors
  /*speed_left = 0;
  speed_right = 50;
  dir_left = false;
  dir_right = true;*/

  //Write signals to GPIO
  analogWrite(PIN_PWM_LEFT, speed_left);
  digitalWrite(PIN_DIR_LEFT, dir_left);

  analogWrite(PIN_PWM_RIGHT, speed_right);
  digitalWrite(PIN_DIR_RIGHT, dir_right);
}

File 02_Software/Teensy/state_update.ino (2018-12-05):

// Function to catch a large difference in an angle when going fro -pi to pi
float angle_diff(float angle2, float angle1)
{
  float diff;
  diff = angle2 - angle1;

  if (diff>M_PI)
    diff -= 2*M_PI;
  else if (diff<-M_PI)
    diff += 2*M_PI;

  return diff;
}

// Function that updates the state, state vector is [x0, y0, phi, alpha, dalpha, v, dphi]
void state_update()
{
  const float wheel_radius = 0.07; // Radius of the wheels, used to compensate angle (encoders also count the relative motion between body and wheel, which does not account for a velocity in "O")
  float alpha, dphi, dphi2, dalpha; //phi

  // Update stuff depending on the mpu
  //phi = (-ypr[0]-mpu_bias[0]);
  alpha = (ypr[1]-mpu_bias[1]);
  dalpha = -0.0244*gyr[1];//(alpha - state[3].floatingPoint)*(1000000/DT);
  dphi = 0.0244*gyr[2];//angle_diff(phi, state[2].floatingPoint)*(1000000/DT);
  dphi2 = (ds_right-ds_left)/(0.1985)*(1000000/DT);

  // limit accelerations to catch/smoothen sensor faults
  /*if (abs(dalpha-state[4].floatingPoint) > 3.0)
  {
   0.0244*gyr[2] dalpha = 0.99*state[4].floatingPoint+0.01*dalpha;
  }*/

  if (abs(float(0.0244*gyr[2]) - dphi2) > 1.0)
  {
    dphi = dphi2;
    //phi = state[2].floatingPoint + dphi*(DT/1000000.0);
  }

  if (abs(float(-0.0244*gyr[1]) - state[4].floatingPoint)>3.0)
  {
    dalpha = 0.995*state[4].floatingPoint + 0.005*dalpha;
    alpha = 0.995*state[3].floatingPoint + 0.005*alpha;
  }

  //state[2].floatingPoint = phi; // gear angle, invert sign because yaw is defined in a strange way
  state[2].floatingPoint += dphi*(DT/1000000.0);
  state[3].floatingPoint = alpha; // tilt angle
  state[4].floatingPoint = dalpha;
  state[6].floatingPoint = dphi;

  // Update states that do not depent on Mpu data
  state[5].floatingPoint = (ds_left + ds_right)/2*(1000000/DT) + state[4].floatingPoint*wheel_radius; // velocity in m/s
  state[0].floatingPoint += cos(state[2].floatingPoint)*state[5].floatingPoint*(DT/1000000.0); // x
  state[1].floatingPoint += sin(state[2].floatingPoint)*state[5].floatingPoint*(DT/1000000.0); // y

  newdata = true; //set flag to send the data to the raspberry pi
}
